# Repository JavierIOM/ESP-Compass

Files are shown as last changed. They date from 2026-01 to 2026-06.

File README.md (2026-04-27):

# ESP32 Digital Compass

**Version 2.0.0**

A remote-accessible digital compass built with ESP32 and the Adafruit LSM303AGR accelerometer/magnetometer. Optional support for BME280 (temperature/humidity/pressure), OLED display, and GPS. The ESP32 creates its own WiFi access point — perfect for field use. Access your compass from any device with a real-time web interface.

## Features

- Real-time tilt-compensated compass heading
- 16-point cardinal direction display (N, NNE, NE, etc.)
- One-button spin calibration with hard-iron offset, soft-iron scale, and north alignment
- EMA-filtered sensor inputs for stable readings
- 10-sample circular mean heading smoothing
- Blinking UNCALIBRATED warning when no valid calibration is stored
- Live magnetometer readings (X, Y, Z axes)
- **Optional BME280** for temperature, humidity, and pressure
- **Optional 0.96" OLED display** showing heading, direction, grid square, temperature, WiFi info
- **Optional GPS module** for location and Maidenhead grid square calculation
- WebSocket-based real-time updates (10Hz)
- CRT/radar terminal aesthetic — green on black
- Dark/Light mode toggle (dark mode default)
- Works on any device with a web browser
- Access Point mode — no existing WiFi network required

## Hardware Requirements

### Bill of Materials (UK)

All parts available from **The Pi Hut** (UK):

| Component | Product | Price | Link |
|---|---|---|---|
| ESP32 Board | FireBeetle ESP32 IoT Microcontroller | ~£8-10 | [The Pi Hut](https://thepihut.com/products/firebeetle-esp32-iot-microcontroller-supports-wi-fi-bluetooth) |
| Sensor | Adafruit LSM303AGR Accelerometer/Magnetometer (ID: 4413) | ~£8-10 | [The Pi Hut](https://thepihut.com/products/adafruit-lsm303agr-accelerometer-magnetometer-stemma-qt-qwiic) |
| Cable | STEMMA QT to Male Header Cable (150mm) | ~£1 | [The Pi Hut](https://thepihut.com/products/stemma-qt-qwiic-jst-sh-4-pin-to-premium-male-headers-cable) |
| USB Cable | USB Cable (Micro-USB or USB-C) | Included | Usually comes with board |
| Environmental Sensor (Optional) | Adafruit BME280 with STEMMA QT (ID: 2652) | ~£15-18 | [The Pi Hut](https://thepihut.com/products/adafruit-bme280-i2c-or-spi-temperature-humidity-pressure-sensor) |
| STEMMA QT Cable (Optional) | STEMMA QT to STEMMA QT Cable (100mm) | ~£1 | [The Pi Hut](https://thepihut.com/products/stemma-qt-qwiic-jst-sh-4-pin-cable-100mm-long) |
| OLED Display (Optional) | 0.96" OLED Display Module (128x64, I2C) | ~£4 | [The Pi Hut](https://thepihut.com/products/0-96-oled-display-module-128x64) |
| GPS Module (Optional) | Adafruit Mini GPS PA1010D (STEMMA QT) | ~£30 | [The Pi Hut](https://thepihut.com/products/adafruit-mini-gps-pa1010d-uart-and-i2c-stemma-qt) |

**Total Cost: ~£17-21** (base) or with optional extras:
- With BME280: ~£33-40
- With OLED: ~£21-25
- With GPS: ~£32-46
- Fully loaded: ~£51-69

### Why FireBeetle ESP32?

- **Low Power:** Ultra-low power consumption design, perfect for battery operation
- **Built-in LiPo Support:** Battery connector with onboard charging circuit
- **Compact Design:** Smaller than standard ESP32 DevKit boards
- **I2C Ready:** GPIO21 (SDA) and GPIO22 (SCL) match our code perfectly

### About the Cable

**IMPORTANT:** The LSM303AGR uses **STEMMA QT** connectors (JST-SH, 1mm pitch).
- Use: STEMMA QT / Qwiic / JST-SH cables
- Don't use: STEMMA (JST-PH, 2mm pitch) — won't fit

## Wiring

All components connect to the FireBeetle ESP32 via I2C. STEMMA QT / Qwiic cables make wiring simple — no soldering required.

```
     ┌─────────────────┐      ┌─────────────────┐
     │  GPS Module     │      │   OLED Display  │
     │  (PA1010D)      │      │   (SSD1306)     │
     └────┬────────────┘      └────┬────────────┘
          │ STEMMA QT (I2C)        │ I2C
          │                        │
          │                        │    ┌─────────────────┐
          │                        │    │     BME280      │
          │                        │    │ (Environmental) │
          │                        │    └────┬────────────┘
          │                        │         │ STEMMA QT (I2C)
          │                        │         │
          │                        │    ┌────▼────────────┐
          │                        │    │   LSM303AGR     │
          │                        │    │   (Compass)     │
          │                        │    └────┬────────────┘
          │                        │         │ STEMMA QT to Headers
          │                        │         │
          └────────────────────────┼─────────┤
                                   │         │
     ┌─────────────────────────────▼─────────▼───┐
     │           FireBeetle ESP32                │
     │  I2C Bus: GPIO21 (SDA), GPIO22 (SCL)      │
     │  Power: 3.3V and GND to all devices       │
     └───────────────────────────────────────────┘
```

### LSM303AGR Compass (required)

| Cable Wire | FireBeetle Pin |
|---|---|
| Black | GND |
| Red | 3.3V |
| Blue | GPIO 21 (SDA) |
| Yellow | GPIO 22 (SCL) |

### BME280, OLED, GPS (optional)

All daisy-chain on the same I2C bus via STEMMA QT cables. No extra wiring to the ESP32.

## Software Setup

### PlatformIO (Recommended)

1. Install [VS Code](https://code.visualstudio.com/) and the PlatformIO IDE extension
2. Open this project folder — PlatformIO auto-detects `platformio.ini`
3. Wait for libraries to download (first time only)

#### Build and Upload

```
# Firmware
pio run -t upload

# Web files (SPIFFS)
pio run -t uploadfs
```

Both must be uploaded. Either order is fine.

#### USB Drivers

Windows 10/11 usually installs drivers automatically. If not:
- CH340: https://sparks.gogo.co.nz/ch340.html
- CP2102: https://www.silabs.com/developers/usb-to-uart-bridge-vcp-drivers

## Project Structure

```
ESP-Compass/
├── platformio.ini          # PlatformIO configuration
├── src/
│   └── main.cpp            # Firmware
├── data/
│   └── index.html          # Web interface (uploaded to SPIFFS)
├── case/
│   └── compass_case.scad   # 3D printable case (OpenSCAD)
└── README.md
```

## Usage

### First Use

1. Power on the ESP32 (USB or battery)
2. Connect your device to the **ESP32-Compass** WiFi (password: `compass123`)
3. Open **http://192.168.4.1** in a browser
4. If no calibration has been saved, a blinking red **UNCALIBRATED** warning will show — calibrate before trusting the heading

### Calibration

The compass uses a one-button spin calibration that computes hard-iron offset, soft-iron scale, and north alignment in a single pass.

**Procedure:**

1. Take the device outside away from metal objects
2. Hold it level
3. Point it at magnetic north (use your phone compass if unsure)
4. Press **Start Calibration** in the web UI
5. Slowly rotate the device through a full 360° horizontal spin
6. The progress bar advances as you cover new sectors — it auto-completes at ~89% coverage
7. Calibration is saved to EEPROM and persists across reboots

**Tips:**
- Keep it level throughout — tilt during the spin doesn't matter much, but try to hold level when pressing Start (that's when north is captured)
- Slow is better than fast
- Avoid phones, speakers, and power supplies nearby (30cm+ clearance)

**Clear Calibration:** Press **Clear Calibration** to wipe EEPROM and force recalibration on next boot.

### Tips for Best Results

- Keep the sensor 30cm+ away from speakers, motors, phones, laptops, and power supplies
- Recalibrate if you change environment (e.g., move from indoors to outdoors)
- The OLED display shows the current heading even without a browser connection

### Battery Operation

- LiPo connector: JST 2.0mm on board
- Onboard LiPo charging via USB
- Typical battery life: 8-12 hours with 1000mAh

## 3D Printable Case

A custom case is in the `case/` folder.

- Mounting standoffs for FireBeetle ESP32 (M3) and LSM303AGR (M2.5)
- Flat Li-Po battery compartment (65x36x10mm, 3000mAh)
- USB port cutout
- 5mm perspex/acrylic lid with DXF cutting template

**Print settings:** 0.2mm layer height, 20% infill, no supports, PLA or PETG.

## WebSocket Data Format

JSON sent at 10Hz over `/ws`:

```json
{
  "heading": 245.3,
  "direction": "WSW",
  "mag_x": 23.45,
  "mag_y": -12.34,
  "mag_z": 45.67,
  "cal_state": 0,
  "cal_progress": 0,
  "calibrated": 1,
  "temperature": 22.5,
  "humidity": 45.2,
  "pressure": 1013.25,
  "gps_has_fix": true,
  "gps_lat": 54.1234,
  "gps_lon": -4.5678,
  "gps_sats": 8,
  "gps_alt": 125.5,
  "gps_speed": 0.0,
  "grid_square": "IO74re"
}
```

- `cal_state`: 0 = idle, 1 = spinning
- `cal_progress`: 0–100% coverage of the 360° spin
- `calibrated`: 1 = valid calibration loaded, 0 = uncalibrated
- Environmental and GPS fields only present when those sensors are connected

## Troubleshooting

**"Could not find LSM303AGR"** — check all 4 wire connections; verify cable is STEMMA QT not STEMMA

**Heading is wrong** — run calibration; avoid nearby magnets/metal

**UNCALIBRATED warning showing** — press Start Calibration and do a slow 360° spin

**Calibration stuck at low %** — you may have magnetic interference nearby; move outside and retry

**Can't see ESP32-Compass WiFi** — wait 10 seconds after power-on; press RST if needed

**Page won't load** — confirm you're on the ESP32-Compass network; verify SPIFFS was uploaded

**Upload fails** — check it's a data cable not a charge-only cable; try BOOT button during upload

## Technical Details

**FireBeetle ESP32:** ESP-WROOM-32, dual-core Xtensa LX6, 240MHz, 802.11 b/g/n WiFi, LiPo charging

**LSM303AGR:** ±2/4/8/16g accelerometer, ±50 gauss magnetometer, 16-bit, I2C 0x19/0x1E

**Heading pipeline:**
1. Raw accel + mag read at 10Hz
2. EMA filter (α=0.2) on both axes
3. Pitch = `asin(-ax)`, Roll = `atan2(ay, az)`
4. Tilt-compensated mag components
5. `atan2` for heading
6. Hard-iron offset and soft-iron scale applied
7. 10-sample circular mean smoothing
8. North heading offset applied

## Dependencies

Managed automatically by PlatformIO:

- Adafruit Unified Sensor
- Adafruit LSM303 Accel
- Adafruit LIS2MDL
- Adafruit BME280 Library
- Adafruit SSD1306 + GFX Library
- Adafruit GPS Library
- AsyncTCP
- ESPAsyncWebServer

## Version History

- **v2.0.0** (April 2026) — **Accuracy Overhaul + Spin Calibration**
  - Replaced 4-point N/E/S/W calibration with one-button 360° spin calibration
  - Spin calibration now computes hard-iron offset, soft-iron scale, AND north heading alignment
  - Fixed roll calculation: `asin(ay/cos_pitch)` → `atan2(ay, az)` — stable across ±180°, no gimbal lock
  - Added EMA filter (α=0.2) on raw accel + mag before tilt compensation
  - Increased heading smoothing from 5 to 10 samples
  - Added blinking UNCALIBRATED warning in UI
  - Fixed sector tracking using centre-relative angle (large hard-iron offsets no longer prevent calibration completing)
  - Fixed minimum range gate — noise no longer instantly fills all sectors at spin start
  - Fixed north offset captured with tilt-compensated formula (not flat-plane)
  - Fixed clearCal not persisting — now writes invalid EEPROM magic so reboot correctly shows UNCALIBRATED
  - Fixed needle 360° wrap-around spin using cumulative rotation with shortest-path delta
  - EEPROM magic bumped to `0xCAF4` (backward-compatible with `0xCAF2`, `0xCAFE`)

- **v1.0.1** (January 2025) — **Hardware Tested with GPS**
  - Switched GPS from Serial UART to I2C (Adafruit Mini GPS PA1010D via STEMMA QT)
  - Fixed false OLED detection when display not connected
  - Improved JavaScript robustness

- **v1.0.0** (January 2025) — **First Stable Release**
  - Core features fully tested: compass heading, calibration, BME280 environmental data

- **v0.0.6** (January 2025)
  - Optional OLED display and GPS module support
  - Maidenhead grid square calculation

- **v0.0.5** (January 2025)
  - Optional BME280 environmental sensor
  - Redesigned 3D printed case

- **v0.0.4** (January 2025)
  - Fixed compass needle rotating wrong direction
  - 5-sample circular mean filter

- **v0.0.3** (January 2025)
  - Magnetometer calibration via web interface
  - EEPROM storage

- **v0.0.2** (January 2025)
  - Fixed tilt compensation division-by-zero
  - Pre-allocated JSON buffer

- **v0.0.1** (January 2025)
  - Initial PlatformIO setup, WebSocket, dark/light mode

## License

Open source. Free to modify, distribute, and use for any purpose.

## Credits

Hardware: Espressif (ESP32), STMicroelectronics (LSM303AGR), DFRobot (FireBeetle), Adafruit (breakout boards)

Software: Adafruit sensor libraries, ESPAsyncWebServer/AsyncTCP

---

Built with ESP32 and Adafruit LSM303AGR | April 2026

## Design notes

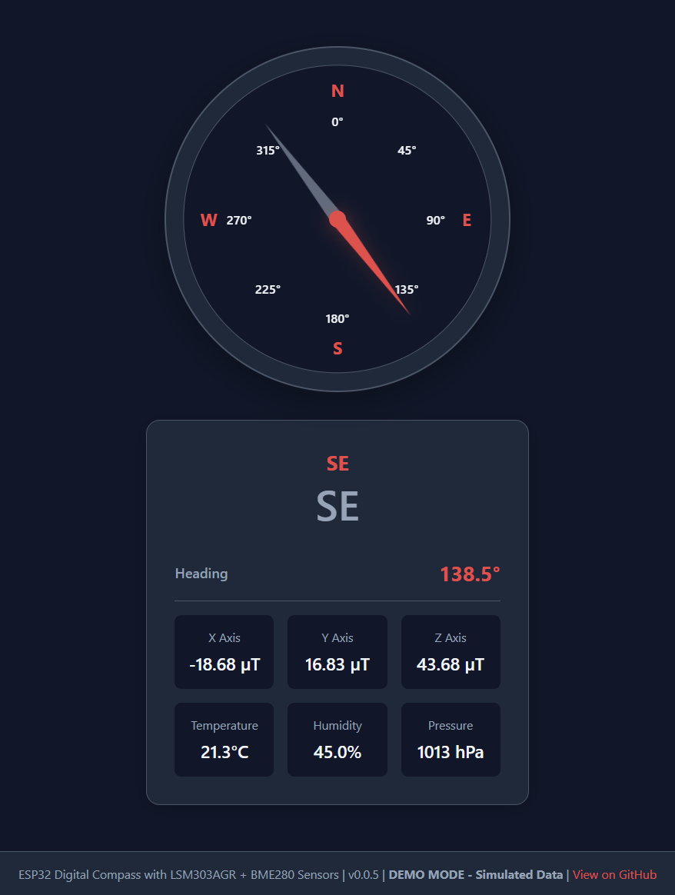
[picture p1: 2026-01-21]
docs/screenshot.png

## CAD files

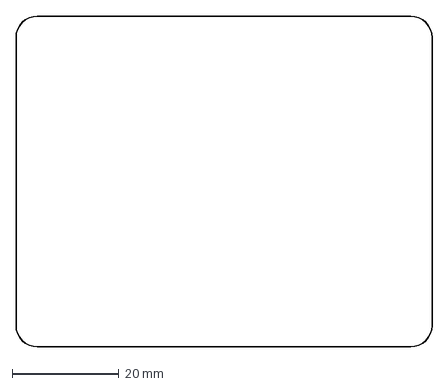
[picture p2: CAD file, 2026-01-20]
case/lid_template.dxf
78.0 x 62.0 mm

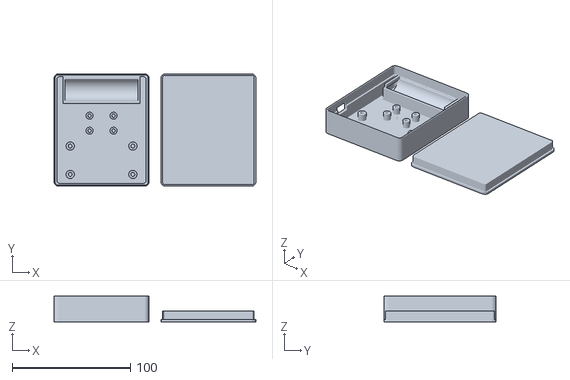
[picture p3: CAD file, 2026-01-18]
case/ESP32-Digital-Compass-Case.stl
171.0 x 95.2 x 21.6

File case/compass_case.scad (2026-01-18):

// ESP32 Digital Compass Case
// Designed for FireBeetle ESP32 V3.0 + Adafruit LSM303AGR + 18650 Battery
// Version 1.0
//
// Print settings:
// - Layer height: 0.2mm
// - Infill: 20%
// - Supports: Not required
// - Material: PLA or PETG

/* [Case Options] */
// Generate the bottom case
generate_bottom = true;
// Generate the lid
generate_lid = true;

/* [Tolerances] */
// Extra clearance for board fit (adjust if too tight/loose)
board_tolerance = 0.3;
// Screw hole tolerance
screw_tolerance = 0.2;
// Gap between lid and case walls (for easy fit)
lid_gap = 0.5;

/* [FireBeetle ESP32 V3.0 Dimensions] */
fb_length = 58;          // mm
fb_width = 29;           // mm
fb_thickness = 1.6;      // mm
fb_hole_dia = 3.1;       // Mounting holes
fb_hole_x_spacing = 53;  // along length
fb_hole_y_spacing = 24;  // along width
fb_hole_x_offset = (fb_length - fb_hole_x_spacing) / 2;
fb_hole_y_offset = (fb_width - fb_hole_y_spacing) / 2;

/* [Adafruit LSM303AGR Dimensions] */
lsm_length = 25.4;       // mm (1.0")
lsm_width = 17.7;        // mm (0.7")
lsm_thickness = 1.6;     // mm
lsm_hole_dia = 2.5;      // Mounting holes
lsm_hole_x_spacing = 20.32;
lsm_hole_y_spacing = 12.7;
lsm_hole_x_offset = (lsm_length - lsm_hole_x_spacing) / 2;
lsm_hole_y_offset = (lsm_width - lsm_hole_y_spacing) / 2;

/* [18650 Battery Dimensions] */
// MUST BE DEFINED BEFORE Case Dimensions!
battery_diameter = 18.5;   // mm (with tolerance)
battery_length = 65.5;     // mm (with tolerance)
battery_holder_wall = 2;   // Wall thickness for battery cradle

/* [Screw Specifications] */
m3_hole = 3.2;
m3_head_dia = 6;
m3_head_height = 2;
m25_hole = 2.7;
m25_head_dia = 5;

/* [Port Cutouts] */
usb_width = 12;
usb_height = 7;

/* [Case Dimensions] */
wall_thickness = 2.5;
floor_thickness = 2;
standoff_height = 6;
lid_height = 8;
lid_lip = 1.5;

// Cradle dimensions (calculated from battery)
cradle_width = battery_diameter + 2 * battery_holder_wall;  // ~22.5mm
cradle_height = battery_diameter / 2 + battery_holder_wall;  // ~11.25mm (lowered)

// Internal dimensions - sized for all components
internal_length = battery_length + 10;  // ~75.5mm (battery is longest)
internal_width = fb_width + 8 + lsm_width + 8 + cradle_width + 5;  // boards + gaps + battery + margin
internal_height = max(standoff_height + fb_thickness + 12, cradle_height + 5);

// External dimensions
case_length = internal_length + 2 * wall_thickness;
case_width = internal_width + 2 * wall_thickness;
case_height = internal_height + floor_thickness;

// ============================================
// MODULES
// ============================================

module rounded_box(length, width, height, radius) {
    hull() {
        translate([radius, radius, 0])
            cylinder(h=height, r=radius, $fn=32);
        translate([length-radius, radius, 0])
            cylinder(h=height, r=radius, $fn=32);
        translate([radius, width-radius, 0])
            cylinder(h=height, r=radius, $fn=32);
        translate([length-radius, width-radius, 0])
            cylinder(h=height, r=radius, $fn=32);
    }
}

module standoff(height, outer_dia, hole_dia) {
    difference() {
        cylinder(h=height, d=outer_dia, $fn=32);
        translate([0, 0, -0.1])
            cylinder(h=height+0.2, d=hole_dia, $fn=32);
    }
}

module firebeetle_standoffs() {
    positions = [
        [fb_hole_x_offset, fb_hole_y_offset],
        [fb_hole_x_offset + fb_hole_x_spacing, fb_hole_y_offset],
        [fb_hole_x_offset, fb_hole_y_offset + fb_hole_y_spacing],
        [fb_hole_x_offset + fb_hole_x_spacing, fb_hole_y_offset + fb_hole_y_spacing]
    ];
    for (pos = positions) {
        translate([pos[0], pos[1], 0])
            standoff(standoff_height, m3_head_dia + 1, m3_hole + screw_tolerance);
    }
}

module lsm303_standoffs() {
    positions = [
        [lsm_hole_x_offset, lsm_hole_y_offset],
        [lsm_hole_x_offset + lsm_hole_x_spacing, lsm_hole_y_offset],
        [lsm_hole_x_offset, lsm_hole_y_offset + lsm_hole_y_spacing],
        [lsm_hole_x_offset + lsm_hole_x_spacing, lsm_hole_y_offset + lsm_hole_y_spacing]
    ];
    for (pos = positions) {
        translate([pos[0], pos[1], 0])
            standoff(standoff_height, m25_head_dia + 1, m25_hole + screw_tolerance);
    }
}

module battery_cradle() {
    // Simple U-shaped cradle - solid block with half-cylinder carved out
    difference() {
        // Solid base block
        cube([battery_length, cradle_width, cradle_height]);

        // Carve U-channel for battery (half-cylinder from top)
        translate([-1, cradle_width/2, cradle_height])
            rotate([0, 90, 0])
                cylinder(h=battery_length + 2, d=battery_diameter, $fn=48);
    }

    // End lips to retain battery
    lip_height = 3;
    lip_width = battery_holder_wall;

    // Left lip
    translate([0, battery_holder_wall, cradle_height])
        cube([lip_width, battery_diameter, lip_height]);

    // Right lip
    translate([battery_length - lip_width, battery_holder_wall, cradle_height])
        cube([lip_width, battery_diameter, lip_height]);
}

module case_bottom() {
    // Component positions (all relative to case origin)
    fb_x = wall_thickness + (internal_length - fb_length) / 2;
    fb_y = wall_thickness + 5;

    lsm_x = wall_thickness + (internal_length - lsm_length) / 2;
    lsm_y = fb_y + fb_width + 8;

    battery_x = wall_thickness + (internal_length - battery_length) / 2;
    battery_y = lsm_y + lsm_width + 8;

    difference() {
        union() {
            // Main case shell
            difference() {
                rounded_box(case_length, case_width, case_height, 4);

                // Hollow interior
                translate([wall_thickness, wall_thickness, floor_thickness])
                    rounded_box(internal_length, internal_width, internal_height + 1, 2);

                // Lid lip recess
                translate([wall_thickness - lid_lip, wall_thickness - lid_lip, case_height - lid_height])
                    rounded_box(internal_length + 2*lid_lip, internal_width + 2*lid_lip, lid_height + 1, 2);
            }

            // FireBeetle standoffs
            translate([fb_x, fb_y, floor_thickness])
                firebeetle_standoffs();

            // LSM303AGR standoffs
            translate([lsm_x, lsm_y, floor_thickness])
                lsm303_standoffs();

            // Battery cradle
            translate([battery_x, battery_y, floor_thickness])
                battery_cradle();
        }

        // USB port cutout
        translate([-1, fb_y + (fb_width - usb_width)/2, floor_thickness + standoff_height + fb_thickness])
            cube([wall_thickness + 2, usb_width, usb_height]);
    }

    // Labels engraved on floor
    translate([fb_x + fb_length/2, fb_y + fb_width/2, floor_thickness - 0.4])
        linear_extrude(0.5)
            text("ESP32", size=5, halign="center", valign="center", $fn=32);

    translate([lsm_x + lsm_length/2, lsm_y + lsm_width/2, floor_thickness - 0.4])
        linear_extrude(0.5)
            text("MAG", size=4, halign="center", valign="center", $fn=32);

    translate([battery_x + battery_length/2, battery_y + cradle_width/2, floor_thickness - 0.4])
        linear_extrude(0.5)
            text("18650", size=4, halign="center", valign="center", $fn=32);
}

module case_lid() {
    // Lid top plate
    rounded_box(case_length, case_width, 2, 4);

    // Inner lip (fits into case recess)
    translate([wall_thickness - lid_lip + lid_gap, wall_thickness - lid_lip + lid_gap, 2])
        rounded_box(internal_length + 2*lid_lip - 2*lid_gap,
                   internal_width + 2*lid_lip - 2*lid_gap,
                   lid_height - 1, 1.5);

    // Text on lid
    translate([case_length/2, case_width/2, 2 - 0.3])
        linear_extrude(0.4)
            text("ESP32 COMPASS", size=6, halign="center", valign="center", $fn=32);

    translate([case_length/2, case_width/2 - 10, 2 - 0.3])
        linear_extrude(0.4)
            text("v0.0.4", size=4, halign="center", valign="center", $fn=32);
}

// ============================================
// RENDER
// ============================================

if (generate_bottom && !generate_lid) {
    case_bottom();
}

if (generate_lid && !generate_bottom) {
    case_lid();
}

if (generate_bottom && generate_lid) {
    case_bottom();
    translate([case_length + 10, 0, 0])
        case_lid();
}

// ============================================
// DIMENSIONS INFO
// ============================================
// Case external: ~81mm x ~99mm x ~27mm
// Hardware needed:
// - 4x M3 screws (6-8mm) for FireBeetle
// - 4x M2.5 screws (6-8mm) for LSM303AGR
// - 1x 18650 battery

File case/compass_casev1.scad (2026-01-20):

// ESP32 Digital Compass Case
// Designed for FireBeetle ESP32 V3.0 + Adafruit LSM303AGR + Flat Li-Po Battery
// Version 2.0 - Redesigned for flat battery under FireBeetle
//
// Print settings:
// - Layer height: 0.2mm
// - Infill: 20%
// - Supports: Not required
// - Material: PLA or PETG

/* [Case Options] */
// Generate the bottom case
generate_bottom = true;
// Generate the lid
generate_lid = true;
// Generate the platform (separate part)
generate_platform = true;

/* [Tolerances] */
// Extra clearance for board fit (adjust if too tight/loose)
board_tolerance = 0.3;
// Screw hole tolerance
screw_tolerance = 0.2;
// Gap between lid and case walls (for easy fit)
lid_gap = 0.5;

/* [FireBeetle ESP32 V3.0 Dimensions] */
fb_length = 58;          // mm
fb_width = 29;           // mm
fb_thickness = 1.6;      // mm
fb_hole_dia = 3.1;       // Mounting holes
fb_hole_x_spacing = 53;  // along length
fb_hole_y_spacing = 24;  // along width
fb_hole_x_offset = (fb_length - fb_hole_x_spacing) / 2;
fb_hole_y_offset = (fb_width - fb_hole_y_spacing) / 2;
fb_component_height = 8; // Height of tallest component on bottom of board

/* [Adafruit LSM303AGR Dimensions] */
lsm_length = 25.4;       // mm (1.0")
lsm_width = 17.7;        // mm (0.7")
lsm_thickness = 1.6;     // mm
lsm_hole_dia = 2.5;      // Mounting holes
lsm_hole_x_spacing = 20.32;
lsm_hole_y_spacing = 12.7;
lsm_hole_x_offset = (lsm_length - lsm_hole_x_spacing) / 2;
lsm_hole_y_offset = (lsm_width - lsm_hole_y_spacing) / 2;

/* [Flat Li-Po Battery Dimensions] */
battery_length = 65;     // mm
battery_width = 36;      // mm
battery_thickness = 10;  // mm
battery_tolerance = 1;   // Extra space around battery

/* [Screw Specifications] */
m3_hole = 3.2;
m3_head_dia = 6;
m3_head_height = 2;
m25_hole = 2.7;
m25_head_dia = 5;

/* [Port Cutouts] */
usb_width = 12;
usb_height = 7;

/* [Case Dimensions] */
wall_thickness = 2.5;
floor_thickness = 2;
lid_thickness = 5;      // 5mm perspex lid
lid_recess = 2;         // How deep the lid sits into the case

// Battery compartment (with tolerance)
battery_compartment_length = battery_length + battery_tolerance;
battery_compartment_width = battery_width + battery_tolerance;
battery_compartment_height = battery_thickness + 1; // +1 for clearance

// Platform above battery for FireBeetle
platform_thickness = 2;
fb_standoff_height = 6; // Standoff height for FireBeetle above platform

// Calculate positions - battery is largest, defines case size
internal_length = max(battery_compartment_length, fb_length) + 8;  // ~73mm
internal_width = max(battery_compartment_width, fb_width + lsm_width + 8) + 4; // boards side by side above battery

// Stack heights:
// Floor -> battery -> platform -> FB standoffs -> FB board -> clearance
internal_height = battery_compartment_height + platform_thickness + fb_standoff_height + fb_thickness + 10;

// External dimensions
case_length = internal_length + 2 * wall_thickness;
case_width = internal_width + 2 * wall_thickness;
case_height = internal_height + floor_thickness;

// ============================================
// MODULES
// ============================================

module rounded_box(length, width, height, radius) {
    hull() {
        translate([radius, radius, 0])
            cylinder(h=height, r=radius, $fn=32);
        translate([length-radius, radius, 0])
            cylinder(h=height, r=radius, $fn=32);
        translate([radius, width-radius, 0])
            cylinder(h=height, r=radius, $fn=32);
        translate([length-radius, width-radius, 0])
            cylinder(h=height, r=radius, $fn=32);
    }
}

module standoff(height, outer_dia, hole_dia) {
    difference() {
        cylinder(h=height, d=outer_dia, $fn=32);
        translate([0, 0, -0.1])
            cylinder(h=height+0.2, d=hole_dia, $fn=32);
    }
}

module firebeetle_standoffs() {
    positions = [
        [fb_hole_x_offset, fb_hole_y_offset],
        [fb_hole_x_offset + fb_hole_x_spacing, fb_hole_y_offset],
        [fb_hole_x_offset, fb_hole_y_offset + fb_hole_y_spacing],
        [fb_hole_x_offset + fb_hole_x_spacing, fb_hole_y_offset + fb_hole_y_spacing]
    ];
    for (pos = positions) {
        translate([pos[0], pos[1], 0])
            standoff(fb_standoff_height, m3_head_dia + 1, m3_hole + screw_tolerance);
    }
}

module lsm303_standoffs() {
    positions = [
        [lsm_hole_x_offset, lsm_hole_y_offset],
        [lsm_hole_x_offset + lsm_hole_x_spacing, lsm_hole_y_offset],
        [lsm_hole_x_offset, lsm_hole_y_offset + lsm_hole_y_spacing],
        [lsm_hole_x_offset + lsm_hole_x_spacing, lsm_hole_y_offset + lsm_hole_y_spacing]
    ];
    for (pos = positions) {
        translate([pos[0], pos[1], 0])
            standoff(fb_standoff_height, m25_head_dia + 1, m25_hole + screw_tolerance);
    }
}

module battery_compartment_walls() {
    // Corner posts to hold battery in place
    post_size = 4;
    post_height = battery_compartment_height;

    // Four corner posts
    positions = [
        [0, 0],
        [battery_compartment_length - post_size, 0],
        [0, battery_compartment_width - post_size],
        [battery_compartment_length - post_size, battery_compartment_width - post_size]
    ];

    for (pos = positions) {
        translate([pos[0], pos[1], 0])
            cube([post_size, post_size, post_height]);
    }

    // Side rails to keep battery centered
    rail_width = 2;
    rail_length = 20;

    // Left rail
    translate([battery_compartment_length/2 - rail_length/2, 0, 0])
        cube([rail_length, rail_width, post_height]);

    // Right rail
    translate([battery_compartment_length/2 - rail_length/2, battery_compartment_width - rail_width, 0])
        cube([rail_length, rail_width, post_height]);
}

module platform_with_standoffs() {
    // Platform that sits above battery, with cutout for wire routing
    // This is a SEPARATE printable part

    // FireBeetle position on platform
    fb_x = (internal_length - fb_length) / 2;
    fb_y = 4;

    // LSM303 position on platform
    lsm_x = (internal_length - lsm_length) / 2;
    lsm_y = fb_y + fb_width + 6;

    difference() {
        union() {
            // Solid platform base
            rounded_box(internal_length, internal_width, platform_thickness, 2);

            // FireBeetle standoffs (on top of platform)
            translate([fb_x, fb_y, platform_thickness])
                firebeetle_standoffs();

            // LSM303AGR standoffs (on top of platform)
            translate([lsm_x, lsm_y, platform_thickness])
                lsm303_standoffs();
        }

        // Wire routing cutout (for battery connector)
        translate([internal_length/2 - 10, internal_width/2 - 8, -0.1])
            cube([20, 16, platform_thickness + 0.2]);
    }
}

module case_bottom() {
    // Component positions (all relative to internal origin)
    battery_x = (internal_length - battery_compartment_length) / 2;
    battery_y = (internal_width - battery_compartment_width) / 2;

    platform_z = floor_thickness + battery_compartment_height;

    // FireBeetle centered above battery
    fb_x = (internal_length - fb_length) / 2;
    fb_y = 4; // Offset toward front for USB access
    fb_z = platform_z + platform_thickness;

    difference() {
        union() {
            // Main case shell
            difference() {
                rounded_box(case_length, case_width, case_height, 4);

                // Hollow interior
                translate([wall_thickness, wall_thickness, floor_thickness])
                    rounded_box(internal_length, internal_width, internal_height + 1, 2);

                // Lid recess (for 5mm perspex to sit flush)
                translate([wall_thickness/2, wall_thickness/2, case_height - lid_recess])
                    rounded_box(case_length - wall_thickness, case_width - wall_thickness, lid_recess + 1, 3);
            }

            // Battery compartment walls
            translate([wall_thickness + battery_x, wall_thickness + battery_y, floor_thickness])
                battery_compartment_walls();

            // Platform ledge supports (for the separate platform to rest on)
            platform_ledge_height = 2;
            platform_ledge_width = 3;

            // Front ledge
            translate([wall_thickness, wall_thickness, platform_z - platform_ledge_height])
                cube([internal_length, platform_ledge_width, platform_ledge_height]);

            // Back ledge
            translate([wall_thickness, wall_thickness + internal_width - platform_ledge_width, platform_z - platform_ledge_height])
                cube([internal_length, platform_ledge_width, platform_ledge_height]);

            // Left ledge
            translate([wall_thickness, wall_thickness, platform_z - platform_ledge_height])
                cube([platform_ledge_width, internal_width, platform_ledge_height]);
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

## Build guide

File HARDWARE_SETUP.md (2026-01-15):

# Quick Hardware Setup Guide

## Parts List
- ESP32 Development Board
- Adafruit LSM303AGR (Product ID: 4413)
- STEMMA QT cable OR 4 jumper wires
- USB cable for programming

## Wiring Diagram

```
┌─────────────────┐
│   LSM303AGR     │
│  (Adafruit)     │
└─────────────────┘
      │ │ │ │
      │ │ │ └─── VIN  ──→  3.3V  ─┐
      │ │ └───── GND  ──→  GND   ─┤
      │ └─────── SDA  ──→  GPIO21 ─┤  ┌──────────┐
      └───────── SCL  ──→  GPIO22 ─┼──│  ESP32   │
                                    │  │   Dev    │
                           USB ─────┤  │  Board   │
                                    └──│          │
                                       └──────────┘
```

## Pin Connections

| LSM303AGR | ESP32 Pin | Notes |
|---|---|---|
| VIN | 3.3V | Power supply |
| GND | GND | Ground |
| SDA | GPIO 21 | I2C Data (default) |
| SCL | GPIO 22 | I2C Clock (default) |

## Using STEMMA QT (Solderless)

If you have a STEMMA QT connector on your ESP32:
1. Plug the STEMMA QT cable into the LSM303AGR
2. Plug the other end into your ESP32's STEMMA QT connector
3. Done!

## Important Notes

- **Voltage:** Use 3.3V, not 5V (ESP32 GPIO pins are 3.3V)
- **I2C Addresses:**
  - Accelerometer: 0x19
  - Magnetometer: 0x1E
- **No external pull-up resistors needed** (built into the breakout board)

## Mounting Tips

- Mount the sensor flat and level for best results
- Keep away from magnetic interference (motors, speakers, large metal objects)
- Can be mounted in any orientation, but level is best for accuracy

## Testing the Hardware

After wiring, upload the sketch and open Serial Monitor (115200 baud):
- You should see "LSM303AGR sensors initialized successfully!"
- If you see an error, check your wiring
- The sensor LED should light up when powered

## Troubleshooting

**Problem:** "Could not find LSM303AGR" error

**Solutions:**
1. Check all wire connections
2. Verify 3.3V power is connected
3. Ensure SDA goes to GPIO 21, SCL to GPIO 22
4. Try a different USB cable (some are power-only)
5. Check if sensor LED lights up (indicates power is good)

**Problem:** Sensor found but readings are wrong

**Solutions:**
1. Keep sensor away from magnetic sources
2. Perform calibration (see README.md)
3. Ensure sensor is relatively level

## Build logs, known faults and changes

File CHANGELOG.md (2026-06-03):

# Changelog

All notable changes to ESP-Compass are documented here.

## [2.1.0] — 2026-06-03

### Added
- Manual heading trim: +/-1° and +/-5° buttons in the calibration panel to correct small residual north alignment errors without recalibrating
- Trim offset persisted in EEPROM independently of calibration data — survives reboots
- Trim resets to zero when calibration is cleared
- `trim_offset` field added to WebSocket JSON so the UI stays in sync on reconnect

## [2.0.0] — 2026-04-27

### Added
- One-button spin calibration: point north, press Start, spin 360° — auto-completes at ~89% circle coverage
- Hard-iron offsets, soft-iron ellipse correction, and north heading offset all computed from a single spin
- Tilt-compensated north reference: accelerometer captured at button press, accurate even when not perfectly level
- Blinking red UNCALIBRATED warning in UI when no valid calibration is loaded
- `calibrated` field in WebSocket JSON

### Changed
- Roll calculation switched from `asin(ay/cos_pitch)` to `atan2(ay, az)` — stable across full ±180°, no gimbal lock
- EMA filter (alpha=0.2) applied to raw accelerometer and magnetometer inputs before tilt compensation
- Heading smoothing increased from 5 to 10 circular-mean samples
- Needle uses cumulative rotation with shortest-path delta — no 360° wrap-around spin at 0°/360° boundary
- EEPROM magic bumped to 0xCAF4 (backward-compatible load of 0xCAF2 and 0xCAFE)
- JSON buffer increased to 768 bytes

### Fixed
- Sector tracking used absolute `atan2(rawY, rawX)` — large hard-iron offsets collapsed all readings into a narrow arc. Fixed to use centre-relative angle
- Noise gate now requires both X and Y axis ranges to exceed 10 µT before sector counting starts — prevents instant false completion at spin start
- clearCal now writes 0xFFFF magic directly instead of calling saveCalibration, so reboot correctly shows UNCALIBRATED
- Old EEPROM format branch no longer silently loads corrupt data when `loadBase()` fails

## [1.0.1] — 2025-01-01

### Added
- GPS panel with live OpenStreetMap embed
- Toggleable GPS detail panel (DOP values, UTC time, fix quality)
- GPS speed converted from knots to mph

### Changed
- GPS switched from UART to I2C (Adafruit PA1010D via STEMMA QT)
- JSON buffer increased to 512 bytes for GPS fields
- OLED detection now does I2C bus scan before calling `display.begin()` to prevent false positives

### Fixed
- OLED display overlap — now shows only IP address centred at the bottom

## [1.0.0] — 2025-01-01

### Added
- Radar/CRT terminal theme (green-on-black, scanline overlay, glow effects)
- SVG compass with rotating needle using CSS transforms
- Tilt-compensated heading via LSM303AGR accelerometer + magnetometer
- 4-point cardinal calibration (N/E/S/W)
- BME280 environment panel (temperature, humidity, pressure)
- OLED display support (SSD1306)
- WiFi AP mode: SSID `ESP32-Compass`, password `compass123`
- WebSocket at `/ws` for 10Hz real-time updates
- SPIFFS-hosted web UI

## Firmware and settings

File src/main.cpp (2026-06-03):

#include <Arduino.h>
#include <WiFi.h>
#include <ESPAsyncWebServer.h>
#include <Wire.h>
#include <Adafruit_Sensor.h>
#include <Adafruit_LSM303_Accel.h>
#include <Adafruit_LIS2MDL.h>
#include <Adafruit_BME280.h>
#include <Adafruit_SSD1306.h>
#include <Adafruit_GPS.h>
#include <SPIFFS.h>
#include <EEPROM.h>

// EEPROM configuration
#define EEPROM_SIZE 64
#define CALIBRATION_MAGIC 0xCAF4      // Spin cal: offsets + scale + heading offset
#define CALIBRATION_MAGIC_V3 0xCAF2   // Old: offsets + scale (no heading offset)
#define CALIBRATION_MAGIC_OLD 0xCAFE  // Oldest: offsets only
#define EEPROM_MAGIC_ADDR 0
#define EEPROM_OFFSET_X_ADDR 2
#define EEPROM_OFFSET_Y_ADDR 6
#define EEPROM_OFFSET_Z_ADDR 10
#define EEPROM_SCALE_X_ADDR 14
#define EEPROM_SCALE_Y_ADDR 18
#define EEPROM_HEADING_OFFSET_ADDR 22
#define EEPROM_TRIM_OFFSET_ADDR 26

// Access Point credentials - CHANGE THESE IF DESIRED
const char* ap_ssid = "ESP32-Compass";     // The WiFi network name
const char* ap_password = "compass123";     // Password (min 8 chars, or "" for open network)

// OLED display configuration
#define SCREEN_WIDTH 128
#define SCREEN_HEIGHT 64
#define OLED_RESET -1
#define OLED_I2C_ADDRESS 0x3C

// GPS configuration (I2C via STEMMA QT)
#define GPS_I2C_ADDRESS 0x10

// Create sensor objects
Adafruit_LSM303_Accel_Unified accel = Adafruit_LSM303_Accel_Unified(54321);
Adafruit_LIS2MDL mag = Adafruit_LIS2MDL(12345);
Adafruit_BME280 bme;
Adafruit_SSD1306 display(SCREEN_WIDTH, SCREEN_HEIGHT, &Wire, OLED_RESET);
Adafruit_GPS GPS(&Wire);

// Optional sensor status
bool bmeAvailable = false;
bool oledAvailable = false;
bool gpsAvailable = false;

// GPS data
float gpsLatitude = 0.0;
float gpsLongitude = 0.0;
float gpsAltitude = 0.0;
float gpsSpeed = 0.0;
int gpsSatellites = 0;
bool gpsHasFix = false;
char gridSquare[7] = "------";  // 6-character Maidenhead locator + null
float gpsHDOP = 0.0;
float gpsVDOP = 0.0;
float gpsPDOP = 0.0;
uint8_t gpsFixQuality = 0;
char gpsTime[9] = "--:--:--";   // HH:MM:SS
char gpsDate[11] = "----/--/--"; // YYYY/MM/DD

// Display update timing (slower than sensor updates)
unsigned long lastDisplayUpdate = 0;
const unsigned long displayUpdateInterval = 250; // Update display 4 times per second

// Web server on port 80
AsyncWebServer server(80);
AsyncWebSocket ws("/ws");

// Timing variables
unsigned long lastUpdate = 0;
const unsigned long updateInterval = 100; // Update every 100ms

// Calibration offsets, scale, and heading offset (loaded from EEPROM)
float magOffsetX = 0.0;
float magOffsetY = 0.0;
float magOffsetZ = 0.0;
float magScaleX = 1.0;
float magScaleY = 1.0;
float headingOffset = 0.0; // Corrects heading so north = 0°
float trimOffset = 0.0;    // Manual fine-tune, persisted in EEPROM

// Spin calibration state
enum CalState { CAL_IDLE, CAL_SPINNING };
CalState calState = CAL_IDLE;
float calMinX, calMaxX, calMinY, calMaxY;
float calNorthRawX, calNorthRawY, calNorthRawZ; // Raw mag captured at north reference
float calNorthAccX, calNorthAccY, calNorthAccZ; // Accel captured at north reference (for tilt compensation)
bool calSectors[36];                // 36 sectors × 10° = full circle
int calSectorsVisited = 0;
bool calGateCleared = false;        // true once both axes have enough spread for a reliable centre

// Latest raw magnetometer reading (updated every loop tick)
float latestRawMagX = 0.0;
float latestRawMagY = 0.0;
float latestRawMagZ = 0.0;

// Pre-allocated buffer for JSON to reduce heap fragmentation
char jsonBuffer[768];

// Smoothing filter for heading
#define SMOOTHING_SAMPLES 10
float headingHistory[SMOOTHING_SAMPLES];
int headingIndex = 0;
bool headingBufferFilled = false;

// EMA filter for sensor inputs — reduces noise before it hits the tilt compensation trig
#define EMA_ALPHA 0.2f
float emaAccX = 0.0f, emaAccY = 0.0f, emaAccZ = 0.0f;
float emaMagX = 0.0f, emaMagY = 0.0f, emaMagZ = 0.0f;
bool emaInit = false;

// Whether valid calibration data is loaded
bool calibrationValid = false;

// Forward declarations
void onWebSocketEvent(AsyncWebSocket *server, AsyncWebSocketClient *client,
                      AwsEventType type, void *arg, uint8_t *data, size_t len);
float calculateTiltCompensatedHeading(float ax, float ay, float az, float mx, float my, float mz);
String getCardinalDirection(float heading);
void loadCalibration();
void saveCalibration();
void saveTrim();
void startSpinCalibration();
void updateSpinCalibration();
void computeSpinCalibration();
void updateDisplay(float heading, const String& direction, float temperature);
void calculateGridSquare(float lat, float lon, char* grid);
void processGPS();

void setup() {
  Serial.begin(115200);
  delay(1000);

  Serial.println("\n\nESP32 Digital Compass");
  Serial.println("=====================");

  // Initialize EEPROM
  EEPROM.begin(EEPROM_SIZE);

  // Initialize I2C
  Wire.begin();

  // Initialize sensors
  if (!accel.begin()) {
    Serial.println("ERROR: Could not find LSM303AGR accelerometer!");
    while (1) delay(10);
  }

  if (!mag.begin()) {
    Serial.println("ERROR: Could not find LSM303AGR magnetometer!");
    while (1) delay(10);
  }

  Serial.println("LSM303AGR sensors initialized successfully!");

  // Try to initialize BME280 (optional sensor)
  if (bme.begin(0x76) || bme.begin(0x77)) {
    bmeAvailable = true;
    Serial.println("BME280 sensor found!");
  } else {
    bmeAvailable = false;
    Serial.println("BME280 not found - continuing without environmental data");
  }

  // Try to initialize OLED display (optional)
  // First do an I2C scan to verify a device is actually present at 0x3C
  // (display.begin() can return true even with no device connected)
  Wire.beginTransmission(OLED_I2C_ADDRESS);
  bool oledOnBus = (Wire.endTransmission() == 0);
  if (oledOnBus && display.begin(SSD1306_SWITCHCAPVCC, OLED_I2C_ADDRESS)) {
    oledAvailable = true;
    display.clearDisplay();
    display.setTextColor(SSD1306_WHITE);
    display.setTextSize(1);
    display.setCursor(0, 0);
    display.println("ESP32 Compass");
    display.println("Initializing...");
    display.display();
    Serial.println("OLED display found!");
  } else {
    oledAvailable = false;
    Serial.println("OLED display not found - continuing without display");
  }

  // Try to initialize GPS via I2C (optional - Adafruit Mini GPS PA1010D)
  if (GPS.begin(GPS_I2C_ADDRESS)) {
    gpsAvailable = true;
    GPS.sendCommand("$PMTK314,0,1,0,1,1,0,0,0,0,0,0,0,0,0,0,0,0,0,0*29");  // RMC + GGA + GSA sentences
    GPS.sendCommand(PMTK_SET_NMEA_UPDATE_1HZ);       // 1Hz update rate
    Serial.println("GPS module found on I2C!");
  } else {
    gpsAvailable = false;
    Serial.println("GPS module not found - continuing without GPS");
  }

  // Load calibration from EEPROM
  loadCalibration();

  // Initialize SPIFFS for serving web files
  if (!SPIFFS.begin(true)) {
    Serial.println("ERROR: SPIFFS mount failed!");
    Serial.println("Web interface will not be available.");
    while (1) delay(10);  // Halt execution - web server won't work without SPIFFS
  }

  // Start Access Point
  Serial.println("Starting Access Point...");
  WiFi.softAP(ap_ssid, ap_password);

  IPAddress IP = WiFi.softAPIP();
  Serial.println("Access Point Started!");
  Serial.print("AP SSID: ");
  Serial.println(ap_ssid);
  Serial.print("AP Password: ");
  Serial.println(ap_password);
  Serial.print("IP Address: ");
  Serial.println(IP);

  // Setup WebSocket
  ws.onEvent(onWebSocketEvent);
  server.addHandler(&ws);

  // Serve static files from SPIFFS
  server.serveStatic("/", SPIFFS, "/").setDefaultFile("index.html");

  // Start server
  server.begin();
  Serial.println("Web server started!");
  Serial.println("Connect to WiFi network: " + String(ap_ssid));
  Serial.println("Then visit: http://" + IP.toString());
}

void loop() {
  // Clean up WebSocket clients
  ws.cleanupClients();

  // Process GPS data if available
  processGPS();

  // Read and send compass data at regular intervals
  if (millis() - lastUpdate >= updateInterval) {
    lastUpdate = millis();

    sensors_event_t accel_event;
    sensors_event_t mag_event;

    // Get sensor readings
    accel.getEvent(&accel_event);
    mag.getEvent(&mag_event);

    // Get raw magnetometer values and store for calibration capture
    float raw_mag_x = mag_event.magnetic.x;
    float raw_mag_y = mag_event.magnetic.y;
    float raw_mag_z = mag_event.magnetic.z;
    latestRawMagX = raw_mag_x;
    latestRawMagY = raw_mag_y;
    latestRawMagZ = raw_mag_z;

    // Update spin calibration if active
    updateSpinCalibration();

    // Apply calibration offsets and scale
    float mag_x = (raw_mag_x - magOffsetX) * magScaleX;
    float mag_y = (raw_mag_y - magOffsetY) * magScaleY;
    float mag_z = raw_mag_z - magOffsetZ;

    // EMA filter — smooth sensor inputs before tilt compensation to reduce noise
    if (!emaInit) {
      emaAccX = accel_event.acceleration.x;
      emaAccY = accel_event.acceleration.y;
      emaAccZ = accel_event.acceleration.z;
      emaMagX = mag_x; emaMagY = mag_y; emaMagZ = mag_z;
      emaInit = true;
    }
    emaAccX += EMA_ALPHA * (accel_event.acceleration.x - emaAccX);
    emaAccY += EMA_ALPHA * (accel_event.acceleration.y - emaAccY);
    emaAccZ += EMA_ALPHA * (accel_event.acceleration.z - emaAccZ);
    emaMagX += EMA_ALPHA * (mag_x - emaMagX);
    emaMagY += EMA_ALPHA * (mag_y - emaMagY);
    emaMagZ += EMA_ALPHA * (mag_z - emaMagZ);

    // Calculate heading with tilt compensation using filtered sensor values
    float heading = calculateTiltCompensatedHeading(
      emaAccX, emaAccY, emaAccZ,
      emaMagX, emaMagY, emaMagZ
    );

    // Convert to degrees (0-360)
    heading = heading * 180.0 / PI;
    if (heading < 0) {
      heading += 360.0;
    }

    // Apply smoothing filter (circular average to handle 0/360 wraparound)
    headingHistory[headingIndex] = heading;
    headingIndex = (headingIndex + 1) % SMOOTHING_SAMPLES;
    if (headingIndex == 0) headingBufferFilled = true;

    int samplesToUse = headingBufferFilled ? SMOOTHING_SAMPLES : headingIndex;
    if (samplesToUse > 0) {
      // Use circular mean to handle wraparound at 0/360
      float sinSum = 0, cosSum = 0;
      for (int i = 0; i < samplesToUse; i++) {
        float rad = headingHistory[i] * PI / 180.0;
        sinSum += sin(rad);
        cosSum += cos(rad);
      }
      heading = atan2(sinSum, cosSum) * 180.0 / PI;
      if (heading < 0) heading += 360.0;
    }

    // Apply north offset so calibrated north = 0°, then manual trim
    heading += headingOffset + trimOffset;
    if (heading < 0) heading += 360.0;
    if (heading >= 360.0) heading -= 360.0;

    // Get cardinal direction
    String direction = getCardinalDirection(heading);

    // Read environmental data if available
    float temperature = 0.0;
    float humidity = 0.0;
    float pressure = 0.0;
    if (bmeAvailable) {
      temperature = bme.readTemperature();
      humidity = bme.readHumidity();
      pressure = bme.readPressure() / 100.0F; // Convert to hPa
    }

    // Build JSON with all available data
    int len = snprintf(jsonBuffer, sizeof(jsonBuffer),
      "{\"heading\":%.1f,\"direction\":\"%s\",\"mag_x\":%.2f,\"mag_y\":%.2f,\"mag_z\":%.2f,\"cal_state\":%d,\"cal_progress\":%d,\"calibrated\":%d,\"trim_offset\":%.1f",
      heading, direction.c_str(), mag_x, mag_y, mag_z,
      (int)calState, (calSectorsVisited * 100 / 36), (int)calibrationValid, trimOffset);

    // Add environmental data if available
    if (bmeAvailable) {
      len += snprintf(jsonBuffer + len, sizeof(jsonBuffer) - len,
        ",\"temperature\":%.1f,\"humidity\":%.1f,\"pressure\":%.1f",
        temperature, humidity, pressure);
    }

    // Add GPS data if module is available
    if (gpsAvailable) {
      len += snprintf(jsonBuffer + len, sizeof(jsonBuffer) - len,
        ",\"gps_has_fix\":%s,\"gps_sats\":%d",
        gpsHasFix ? "true" : "false", gpsSatellites);
      if (gpsHasFix) {
        len += snprintf(jsonBuffer + len, sizeof(jsonBuffer) - len,
          ",\"gps_lat\":%.6f,\"gps_lon\":%.6f,\"gps_alt\":%.1f,\"gps_speed\":%.1f,\"grid_square\":\"%s\""
          ",\"gps_hdop\":%.1f,\"gps_vdop\":%.1f,\"gps_pdop\":%.1f,\"gps_fix_quality\":%d,\"gps_time\":\"%s\",\"gps_date\":\"%s\"",
          gpsLatitude, gpsLongitude, gpsAltitude, gpsSpeed, gridSquare,
          gpsHDOP, gpsVDOP, gpsPDOP, gpsFixQuality, gpsTime, gpsDate);
      }
    }

    // Close JSON object
    snprintf(jsonBuffer + len, sizeof(jsonBuffer) - len, "}");

    ws.textAll(jsonBuffer);

    // Update OLED display at slower rate
    if (oledAvailable && (millis() - lastDisplayUpdate >= displayUpdateInterval)) {
      lastDisplayUpdate = millis();
      updateDisplay(heading, direction, temperature);
    }
  }
}

float calculateTiltCompensatedHeading(float ax, float ay, float az, float mx, float my, float mz) {
  // Normalize accelerometer values with division-by-zero protection
  float accel_norm = sqrt(ax * ax + ay * ay + az * az);

  // Protect against division by zero (sensor fault or initialization)
  if (accel_norm < 0.001) {
    accel_norm = 0.001;
  }

  ax /= accel_norm;
  ay /= accel_norm;
  az /= accel_norm;

  // Clamp ax to valid range for asin (-1 to 1) to prevent NaN
  if (ax > 1.0) ax = 1.0;
  if (ax < -1.0) ax = -1.0;

  // Calculate pitch and roll
  // atan2(ay, az) for roll is stable across full ±180° range with no gimbal lock
  float pitch = asin(-ax);
  float roll = atan2(ay, az);

  // Tilt compensated magnetic field components (full 3-axis rotation matrix, Freescale AN4248)
  float cos_pitch = cos(pitch);
  float cos_roll = cos(roll);
  float sin_roll = sin(roll);
  float sin_pitch = sin(pitch);

  float mag_x_comp = mx * cos_pitch + my * sin_roll * sin_pitch + mz * cos_roll * sin_pitch;
  float mag_y_comp = my * cos_roll - mz * sin_roll;

  // Calculate heading (negated to correct for sensor orientation)
  float heading = -atan2(mag_y_comp, mag_x_comp);

  return heading;
}

String getCardinalDirection(float heading) {
  // Convert heading to 16-point compass rose
  static const char* directions[] = {
    "N", "NNE", "NE", "ENE",
    "E", "ESE", "SE", "SSE",
    "S", "SSW", "SW", "WSW",
    "W", "WNW", "NW", "NNW"
  };

  // Ensure heading is in valid range (0-360)
  while (heading < 0) heading += 360.0;
  while (heading >= 360.0) heading -= 360.0;

  // Calculate index safely (always positive due to range normalization above)
  int index = (int)((heading + 11.25) / 22.5) % 16;

  // Extra safety check for index bounds
  if (index < 0) index = 0;
  if (index > 15) index = 15;

  return directions[index];
}

void onWebSocketEvent(AsyncWebSocket *server, AsyncWebSocketClient *client,
                      AwsEventType type, void *arg, uint8_t *data, size_t len) {
  if (type == WS_EVT_CONNECT) {
    Serial.printf("WebSocket client #%u connected from %s\n",
                  client->id(), client->remoteIP().toString().c_str());
  } else if (type == WS_EVT_DISCONNECT) {
    Serial.printf("WebSocket client #%u disconnected\n", client->id());
  } else if (type == WS_EVT_DATA) {
    // Handle incoming data (calibration commands)
    AwsFrameInfo *info = (AwsFrameInfo*)arg;
    if (info->final && info->index == 0 && info->len == len && info->opcode == WS_TEXT) {
      // Copy data to a properly sized buffer for null termination
      char msgBuffer[64];
      size_t copyLen = len < sizeof(msgBuffer) - 1 ? len : sizeof(msgBuffer) - 1;
      memcpy(msgBuffer, data, copyLen);
      msgBuffer[copyLen] = '\0';
      String msg = msgBuffer;
      Serial.printf("WS received: %s\n", msgBuffer);

      if (msg.indexOf("calStart") >= 0) {
        startSpinCalibration();
      } else if (msg.indexOf("clearCal") >= 0) {
        calState = CAL_IDLE;
        magOffsetX = 0.0; magOffsetY = 0.0; magOffsetZ = 0.0;
        magScaleX = 1.0; magScaleY = 1.0;
        headingOffset = 0.0;
        trimOffset = 0.0;
        calibrationValid = false;
        // Write an invalid magic so EEPROM doesn't reload as "calibrated" on next boot
        uint16_t inv = 0xFFFF;
        EEPROM.put(EEPROM_MAGIC_ADDR, inv);
        EEPROM.put(EEPROM_TRIM_OFFSET_ADDR, trimOffset);
        EEPROM.commit();
        Serial.println("Calibration cleared");
      } else if (msg.indexOf("trimSet") >= 0) {
        int idx = msg.indexOf("\"value\":");
        if (idx >= 0) {
          float val = msg.substring(idx + 8).toFloat();
          if (!isnan(val) && !isinf(val)) {
            trimOffset = constrain(val, -45.0f, 45.0f);
            saveTrim();
            Serial.printf("Trim offset set to %.1f°\n", trimOffset);
          }
        }
      }
    }
  }
}

// Load calibration from EEPROM
void loadCalibration() {
  uint16_t magic;
  EEPROM.get(EEPROM_MAGIC_ADDR, magic);

  auto loadBase = [&]() {
    EEPROM.get(EEPROM_OFFSET_X_ADDR, magOffsetX);
    EEPROM.get(EEPROM_OFFSET_Y_ADDR, magOffsetY);
    EEPROM.get(EEPROM_OFFSET_Z_ADDR, magOffsetZ);
    EEPROM.get(EEPROM_SCALE_X_ADDR, magScaleX);
    EEPROM.get(EEPROM_SCALE_Y_ADDR, magScaleY);
    bool valid = true;
    if (isnan(magOffsetX) || isinf(magOffsetX) || fabs(magOffsetX) > 500.0) valid = false;
    if (isnan(magOffsetY) || isinf(magOffsetY) || fabs(magOffsetY) > 500.0) valid = false;
    if (isnan(magOffsetZ) || isinf(magOffsetZ) || fabs(magOffsetZ) > 500.0) valid = false;
    if (isnan(magScaleX)  || isinf(magScaleX)  || magScaleX < 0.1 || magScaleX > 10.0) valid = false;
    if (isnan(magScaleY)  || isinf(magScaleY)  || magScaleY < 0.1 || magScaleY > 10.0) valid = false;
    return valid;
  };

  if (magic == CALIBRATION_MAGIC) {
    if (loadBase()) {
      EEPROM.get(EEPROM_HEADING_OFFSET_ADDR, headingOffset);
      if (isnan(headingOffset) || isinf(headingOffset)) headingOffset = 0.0;
      calibrationValid = true;
      Serial.printf("Calibration loaded: offset=%.2f,%.2f scale=%.3f,%.3f north=%.1f°\n",
        magOffsetX, magOffsetY, magScaleX, magScaleY, headingOffset);
    } else {
      Serial.println("EEPROM calibration invalid - resetting");
      magOffsetX = 0; magOffsetY = 0; magOffsetZ = 0;
      magScaleX = 1; magScaleY = 1; headingOffset = 0;
    }
  } else if (magic == CALIBRATION_MAGIC_V3 || magic == CALIBRATION_MAGIC_OLD) {
    bool valid = false;
    if (magic == CALIBRATION_MAGIC_V3) {
      valid = loadBase();
    } else {
      EEPROM.get(EEPROM_OFFSET_X_ADDR, magOffsetX);
      EEPROM.get(EEPROM_OFFSET_Y_ADDR, magOffsetY);
      EEPROM.get(EEPROM_OFFSET_Z_ADDR, magOffsetZ);
      magScaleX = 1.0; magScaleY = 1.0;
      valid = !(isnan(magOffsetX) || isinf(magOffsetX) || fabs(magOffsetX) > 500.0 ||
               isnan(magOffsetY) || isinf(magOffsetY) || fabs(magOffsetY) > 500.0 ||
               isnan(magOffsetZ) || isinf(magOffsetZ) || fabs(magOffsetZ) > 500.0);
    }
    if (valid) {
      headingOffset = 0.0;
      calibrationValid = true;
      Serial.println("Old calibration format loaded (no north offset — recalibrate for best accuracy)");
    } else {
      Serial.println("Old EEPROM calibration invalid - resetting");
      magOffsetX = 0; magOffsetY = 0; magOffsetZ = 0;
      magScaleX = 1; magScaleY = 1; headingOffset = 0;
    }
  } else {
    Serial.println("No calibration data in EEPROM");
    magOffsetX = 0; magOffsetY = 0; magOffsetZ = 0;
    magScaleX = 1; magScaleY = 1; headingOffset = 0;
  }

  // Load trim offset independently — valid even if calibration is absent
  float savedTrim;
  EEPROM.get(EEPROM_TRIM_OFFSET_ADDR, savedTrim);
  if (isnan(savedTrim) || isinf(savedTrim) || fabs(savedTrim) > 90.0) {
    trimOffset = 0.0;
  } else {
    trimOffset = savedTrim;
  }
  if (trimOffset != 0.0) Serial.printf("Trim offset loaded: %.1f°\n", trimOffset);
}

// Save calibration to EEPROM
void saveCalibration() {
  uint16_t magic = CALIBRATION_MAGIC;
  EEPROM.put(EEPROM_MAGIC_ADDR, magic);
  EEPROM.put(EEPROM_OFFSET_X_ADDR, magOffsetX);
  EEPROM.put(EEPROM_OFFSET_Y_ADDR, magOffsetY);
  EEPROM.put(EEPROM_OFFSET_Z_ADDR, magOffsetZ);
  EEPROM.put(EEPROM_SCALE_X_ADDR, magScaleX);
  EEPROM.put(EEPROM_SCALE_Y_ADDR, magScaleY);
  EEPROM.put(EEPROM_HEADING_OFFSET_ADDR, headingOffset);
  EEPROM.commit();
  calibrationValid = true;
  Serial.println("Calibration saved to EEPROM");
}

// Persist trim offset without touching calibration data
void saveTrim() {
  EEPROM.put(EEPROM_TRIM_OFFSET_ADDR, trimOffset);
  EEPROM.commit();
}

// Begin spin calibration — call when user presses the button pointing north (device must be level)
void startSpinCalibration() {
  calState = CAL_SPINNING;
  calNorthRawX = latestRawMagX;
  calNorthRawY = latestRawMagY;
  calNorthRawZ = latestRawMagZ;
  calNorthAccX = emaAccX;
  calNorthAccY = emaAccY;
  calNorthAccZ = emaAccZ;
  calMinX = calMaxX = latestRawMagX;
  calMinY = calMaxY = latestRawMagY;
  memset(calSectors, 0, sizeof(calSectors));
  calSectorsVisited = 0;
  calGateCleared = false;
  Serial.println("Spin calibration started — spin 360° slowly");
}
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

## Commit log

2026-01-15 Initial commit: ESP32 Digital Compass with Access Point mode
    - ESP32 FireBeetle with LSM303AGR magnetometer sensor
    - Tilt-compensated heading calculation
    - Real-time web interface with WebSocket updates (10Hz)
    - Access Point mode for field use (no existing WiFi needed)
    - Dark/light mode toggle with dark mode default
    - Responsive compass display with animated needle
    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
2026-01-15 Migrate to PlatformIO and add version 0.0.1
    - Add platformio.ini configuration for FireBeetle ESP32
    - Move sketch to src/main.cpp with required forward declarations
    - Update README with PlatformIO setup instructions
    - Remove Arduino IDE specific documentation
    - Mark as v0.0.1 (pre-release, untested on hardware)
2026-01-16 Fix critical bugs and release v0.0.2
    Bug Fixes:
    - Fix division-by-zero in tilt compensation when device tilted near vertical
    - Fix gimbal lock handling when pitch approaches +/-90 degrees
    - Fix potential NaN values from asin() with out-of-range inputs
    - Fix potential negative array index in cardinal direction lookup
    - Fix SPIFFS mount failure to properly halt execution
    Improvements:
    - Replace String concatenation with pre-allocated buffer (prevents heap fragmentation)
    - Add JSON parse error handling in web interface
    - Remove redundant AsyncWebSocket include
    - Add bounds checking throughout compass calculations
    [main.cpp]
2026-01-18 Add magnetometer calibration feature and release v0.0.3
    - Add automatic calibration via web interface with 15-second procedure
    - Store calibration offsets in EEPROM (persists across reboots)
    - Add Calibrate and Clear Calibration buttons to web UI
    - Add real-time countdown timer during calibration
    - Use hard-iron calibration (min/max method) for offset calculation
    - Hardware tested successfully
    [main.cpp]
2026-01-18 Add 3D printable case design for ESP32 Compass
    - OpenSCAD parametric case with FireBeetle and LSM303AGR mounting
    - 18650 battery cradle
    - USB port cutout
    - Snap-fit lid design
    - Updated README with case documentation
    [compass_case.scad]
2026-01-18 Fix heading direction and add smoothing filter for v0.0.4
    - Fixed compass needle rotating in wrong direction (inverted heading)
    - Added 5-sample moving average filter for smoother heading display
    - Uses circular mean algorithm to handle 0°/360° wraparound correctly
    [compass_case.scad]
2026-01-20 Some case mods for a different battery
    [compass_casev1.scad, lid_template.dxf, lid_templatev1.dxf]
2026-01-21 Add optional BME280 temperature/humidity/pressure sensor support
    - Sensor is detected at startup, project runs without it if not present
    - When BME280 is connected, environmental data is sent via WebSocket
    - Web UI shows temperature, humidity, and pressure when available
    - Also includes case redesign for flat 65x36x10mm Li-Po battery
    [main.cpp]
2026-01-21 Bump version to 0.0.5 and update README
    - Added BME280 optional sensor documentation
    - Updated bill of materials with BME280 option
    - Added BME280 wiring instructions
    - Updated case documentation for new flat battery design
    - Added DXF lid template to file list
    - Updated JSON protocol documentation with environmental data
    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
2026-01-21 Add BME280 environmental data to demo.html
    - Added temperature, humidity, and pressure display
    - Simulates BME280 sensor readings with slight variations
    - Updated footer to reflect v0.0.5 and BME280 support
2026-01-21 Update BME280 to Adafruit STEMMA QT version with daisy-chain wiring
2026-01-22 Slow down environmental updates in demo, make GPS static
    Environmental data now updates every 5 seconds with small realistic
    drift instead of jittering 10 times per second. GPS data is now
    completely static since the demo represents a stationary device.
2026-01-24 Add optional OLED display and GPS module support (v0.0.6)
    New features:
    - Optional 0.96" OLED display (SSD1306, I2C at 0x3C)
    - Optional GPS module support (Serial2, GPIO 16/17)
    - Automatic Maidenhead grid square calculation from GPS
    - Display shows: heading, direction, grid square, temp, WiFi info
    - GPS data included in WebSocket JSON when available
    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
2026-01-24 Release v1.0.0 - First stable release
    - Bump version to 1.0.0
    - Add note that OLED and GPS features are not yet hardware tested
    - Add complete system wiring diagram including GPS module
    - Core features fully tested: compass, calibration, BME280
2026-01-24 Clean up README wiring diagrams
    - Consolidated redundant diagrams into single clear system diagram
    - Removed duplicate BME280 daisy-chain diagram
    - Streamlined pin connection tables
    - All components now shown in one overview
2026-01-24 Production readiness fixes from SDET review
    Critical fixes:
    - Fix WebSocket buffer overwrite bug (was writing past allocated buffer)
    - Add GPS data display to production web interface (was missing)
    - Fix Maidenhead grid square to use lowercase subsquares per standard
    - Add boundary handling in grid square calculation
    - Add EEPROM calibration sanity checks (NaN, Inf, out-of-range)
    - Handle GPS fix loss (gpsHasFix now correctly set to false)
    - Fix README line number references (AP config: 22-24, update rate: 68)
    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
    [main.cpp]
2026-01-25 Fix JS robustness issues and README inaccuracies from deep review
    - Fix countdown element reference loss after innerHTML reset (re-query by ID)
    - Add null/undefined validation for required compass data fields
    - Add GPS coordinate validation (-90/90 lat, -180/180 lon)
    - Fix misleading static "3D" GPS fix indicator - now shows actual fix status
    - Fix README compass rose description (45 degrees, not 60)
    - Update README JSON example with all fields (calibration, GPS)
2026-01-30 Remove verbose raw sensor debug output from serial
2026-01-30 Fix false OLED detection when display not connected
    display.begin() can return true even without a device present.
    Added I2C bus scan check before calling begin().
    [main.cpp]
2026-01-30 Switch GPS from Serial UART to I2C (Adafruit PA1010D)
    GPS module uses STEMMA QT (I2C) not serial pins. Replaced TinyGPS++
    with Adafruit GPS Library for native I2C support at address 0x10.
    - GPS now auto-detected on I2C bus like other sensors
    - Sends gps_has_fix field even without fix (UI shows "No Fix")
    - Updated README wiring diagram (all devices on I2C)
    - Updated BOM with specific PA1010D module
    [main.cpp]
2026-01-30 Add toggleable GPS detail panel with DOP, time, and fix quality
    Shows HDOP, VDOP, PDOP, UTC time/date, and fix quality behind
    a "Show Details" toggle button. Enabled GSA sentences for DOP data.
    [main.cpp]
2026-01-30 Increase JSON buffer from 384 to 512 bytes for GPS detail fields
    The added GPS detail fields (DOP, time, date, fix quality) caused
    the JSON to exceed the 384-byte buffer, resulting in no data sent.
    [main.cpp]
2026-01-30 Add live OpenStreetMap embed to GPS panel
    Map shows current position when GPS has fix. Only reloads iframe
    when position changes by >0.0005 degrees to avoid excessive reloads.
    Map loads on the phone's internet, no extra load on the ESP32.
2026-01-31 Fix OLED display overlap by showing only IP address centered
    SSID (78px) + IP (66px) exceeded 128px screen width. Replaced with
    just the centered IP address since the SSID is static/known.
    [main.cpp]
2026-02-01 Redesign web UI with radar/CRT terminal theme
    Replace modern card-based UI with ship's radar aesthetic:
    - Green-on-black CRT color scheme with phosphor glow effects
    - SVG radar compass with concentric rings, tick marks, crosshair
    - Monospace font throughout (Courier New/Consolas)
    - Scanline overlay for CRT authenticity
    - Dashed-border terminal-style data panels
    - Map iframe gets hue-rotate filter to match green theme
    - Remove light/dark theme toggle (always radar green)
    - All existing functionality preserved (WebSocket, calibration,
    GPS details toggle, map embed)
2026-02-01 Fix missing compass needle by using CSS transforms for SVG rotation
    SVG attribute transform with pixel-based transform-origin was not
    rendering the needle. Switched to CSS transform with transform-box:
    fill-box and percentage-based origin for reliable SVG rotation.
2026-02-12 Replace spin calibration with 4-point cardinal calibration
    Old calibration (spin for 15s, track min/max) was inaccurate and only
    did hard-iron offset correction. New system: point compass N/E/S/W and
    click each button. Computes both hard-iron offsets (center of ellipse)
    and soft-iron scale factors (normalize ellipse to circle).
    Firmware:
    - 4 WebSocket commands: calN, calE, calS, calW
    - Auto-computes calibration when all 4 points captured
    - New EEPROM format (0xCAF2) stores offsets + scale factors
    - Backward compatible with old EEPROM format (0xCAFE)
    Web UI:
    - 4 cardinal buttons [N] [E] [S] [W] with captured state glow
    - [CLEAR CALIBRATION] button
    - Status message on completion
    Co-Authored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
    [main.cpp]
2026-02-12 Add visual feedback and debug logging for calibration buttons
    Buttons now flash green immediately on click so you can see the tap registered,
    and show 'NOT CONNECTED' if WebSocket is down. Firmware logs received WS
    messages to serial for troubleshooting.
2026-04-26 Overhaul compass accuracy: EMA filter, better roll calc, calibration status
    - Replace asin(ay/cos_pitch) roll with atan2(ay, az) — stable across full range,
    no gimbal lock discontinuities
    - Add EMA filter (alpha=0.2) on accel and mag inputs before tilt compensation
    to reduce noise amplification through trig functions
    - Increase heading smoothing from 5 to 10 samples
    - Add calibrationValid flag sent in JSON as 'calibrated'
    - UI shows blinking red warning when no calibration data is loaded
    [main.cpp]
2026-04-26 Replace 4-point calibration with one-button spin calibration
    Point north, press Start, spin 360° slowly - auto-completes when 32/36
    angular sectors have been covered (~89% of the circle).
    Calibration now computes:
    - Hard-iron offsets (min/max envelope centre)
    - Soft-iron X/Y scale (normalise ellipse to circle)
    - North heading offset (so the sensor reads 0° when pointing north)
    EEPROM format bumped to 0xCAF4 (backward-compatible load of old formats).
    UI shows a progress bar filling as you spin.
    [main.cpp]
2026-04-27 Fix spin calibration sector tracking and three bugs found in audit
    - Fix sector tracking using centre-relative angle so hard-iron offset
    doesn't collapse all readings into a narrow arc (was: 13% max progress)
    - Fix clearCal writing invalid magic instead of calling saveCalibration(),
    which was silently re-marking the device as calibrated with zero offsets
    - Fix north offset captured with tilt-compensated heading (captures accel
    at button press) instead of flat-plane atan2, so the offset is accurate
    even when not perfectly level at the moment of pressing Start
    - Fix V3/old EEPROM branch ignoring loadBase() validity return value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
    [main.cpp]
2026-04-27 Fix calibration noise gate and needle wrap-around
    - Add 5 µT range gate before sector tracking — without it, atan2(~0,~0)
    from sensor noise at spin start covers all 36 sectors instantly
    - Fix needle 360° spin on 358°→2° transitions using cumulative rotation
    with shortest-path delta instead of raw heading value
    [main.cpp]
2026-04-27 Update README to v2.0.0 — full rewrite for spin calibration
    Documents current calibration procedure, heading pipeline, accurate
    JSON format, and full version history up to v2.0.0.
2026-04-27 Fix tilt compensation formula, pin platform, increase JSON buffer
    - Fix mag_x_comp to include My·sin(roll)·sin(pitch) and use
    Mz·cos(roll)·sin(pitch) — was the simplified form that drops the
    My cross term and gets the Mz coefficient wrong at combined pitch+roll
    - Fix mag_y_comp: remove incorrect Mx·sin(roll)·sin(pitch) term,
    simplified correctly to My·cos(roll) - Mz·sin(roll)
    - Pin platform = espressif32@6.13.0 to prevent unexpected breakage
    - Add monitor_filters = esp32_exception_decoder for readable stack traces
    - Increase JSON buffer 512 → 768 to avoid silent truncation with full GPS
    - Improve CALIBRATION_MAGIC_OLD validity check: match loadBase() range
    checks (isinf +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
    [main.cpp]
2026-04-27 Fix calibration gate: require both axes >10uT before counting sectors
    The previous gate (either axis >5uT) cleared too early with a bad centre
    estimate, wasting ~4-5 sectors and leaving the spin stuck at 77%. Fix:
    - Require both X and Y ranges to exceed 10uT before counting (needs ~30-45
    degrees of actual rotation, giving a stable centre estimate)
    - Reset sector map on gate clearance so early garbage sectors are discarded
    and counting starts clean from the stable centre
    [main.cpp]
2026-06-03 Add manual heading trim with EEPROM persistence
    +/-1 and +/-5 degree buttons in the calibration panel let you nudge the
    heading after calibration without recalibrating. Trim is stored separately
    in EEPROM so it survives reboots and is cleared when calibration is cleared.
    [main.cpp]
